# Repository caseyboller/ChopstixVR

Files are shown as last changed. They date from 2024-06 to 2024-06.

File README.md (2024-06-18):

A prototype I made in 2020 for a haptic chopstick to be used in VR, developed from PCB to Unity/Arduino.

Prototype
 
[Design](https://github.com/caseyboller/ChopstixVR/assets/36660680/1214c257-8176-43c2-80a8-be5d32b23608)

[CAD design](https://github.com/caseyboller/ChopstixVR/assets/36660680/7751c19b-aa32-42bb-81e6-dfa4c7f0dddc)

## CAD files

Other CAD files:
case/Chopstix.f3z
case/Control Board.f3z

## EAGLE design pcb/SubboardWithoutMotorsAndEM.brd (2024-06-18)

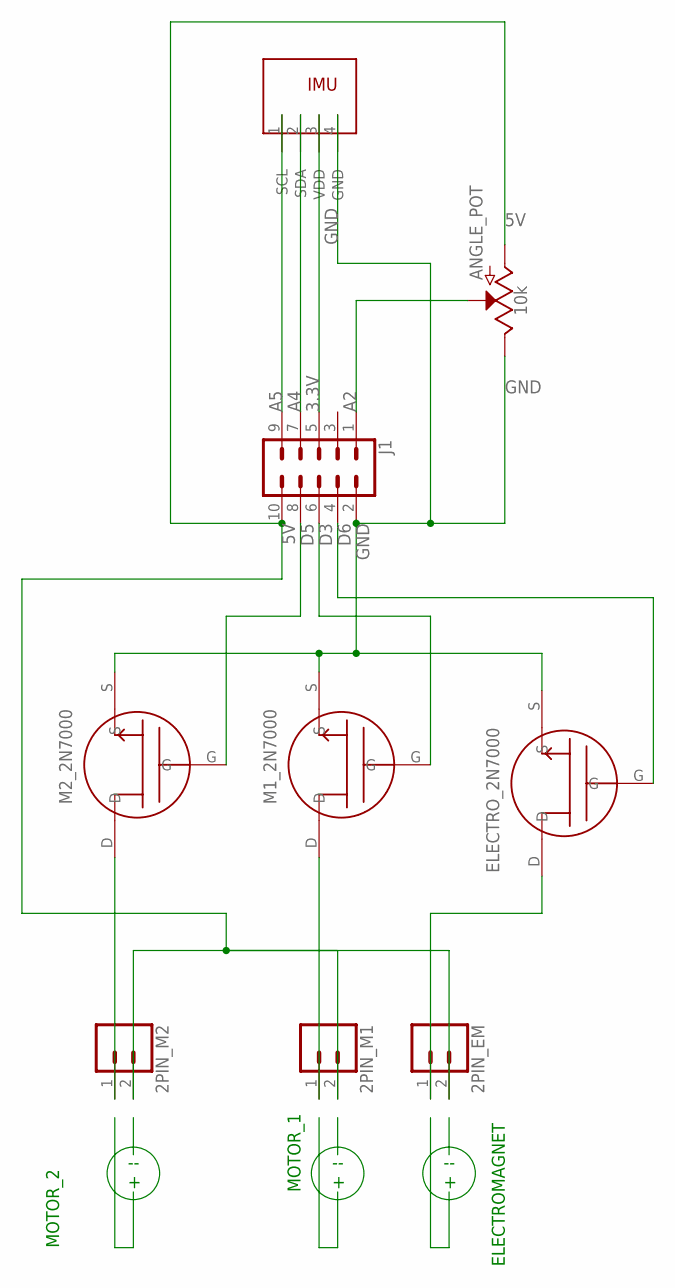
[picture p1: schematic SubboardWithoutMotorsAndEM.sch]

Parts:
2PIN_EM, 2PIN_M1, 2PIN_M2: CONN_02; 1X02
ANGLE_POT: 10k; POT-PTH-ALPS-KIT
ELECTRO_2N7000: 2N7000_N_FET
J1: CONN_05X2SHD; 2X5-SHROUDED
M1_2N7000, M2_2N7000: 2N7000_N_FET
U$1: MPU-9250

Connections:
3.3V: J1.5, U$1.3 (VDD)
5V: 2PIN_EM.2, 2PIN_M1.2, 2PIN_M2.2, ANGLE_POT.P$3 (A), J1.10
A2: ANGLE_POT.P$2 (S), J1.1
A4: J1.7, U$1.2 (SDA)
A5: J1.9, U$1.1 (SCL)
D3: J1.6, M1_2N7000.G
D5: J1.8, M2_2N7000.G
D6: ELECTRO_2N7000.G, J1.4
GND: ANGLE_POT.P$1 (E), ELECTRO_2N7000.S, J1.2, M1_2N7000.S, M2_2N7000.S, U$1.4 (GND)
unnamed: 2PIN_M2.1, M2_2N7000.D
unnamed: 2PIN_M1.1, M1_2N7000.D
unnamed: 2PIN_EM.1, ELECTRO_2N7000.D

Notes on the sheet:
MOTOR_2
MOTOR_1
ELECTROMAGNET
-- +

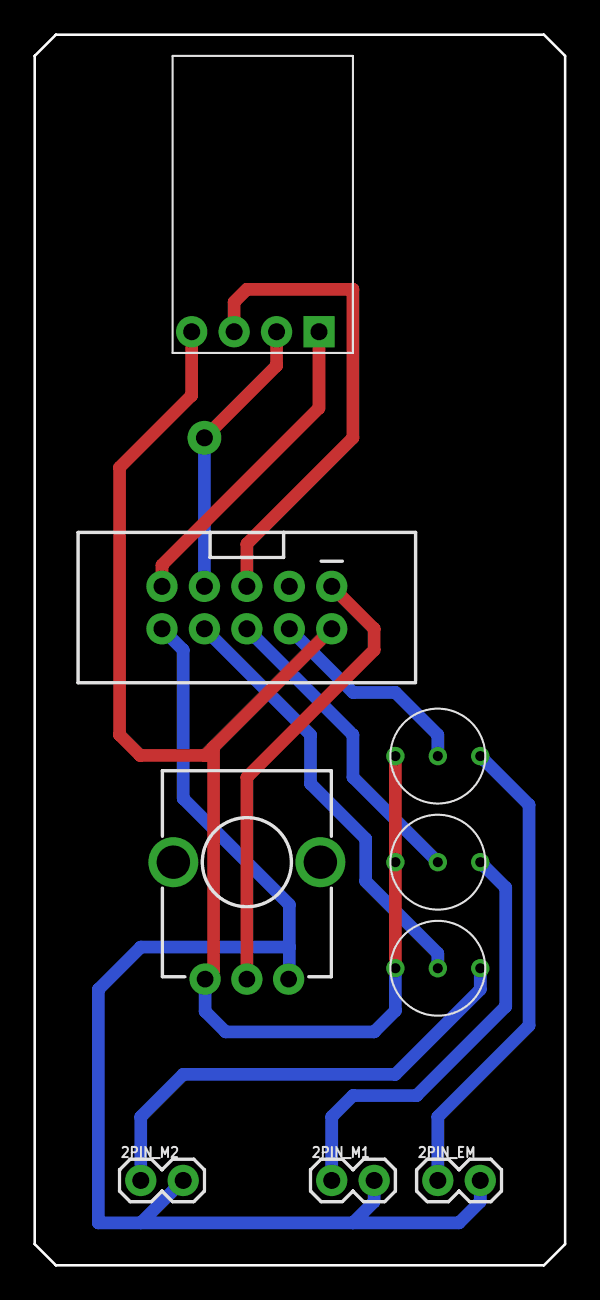
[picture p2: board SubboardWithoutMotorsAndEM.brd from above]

Board: 2 copper layers, 31.7 x 73.7 mm, 9 parts (0 on the bottom side), 12 nets.

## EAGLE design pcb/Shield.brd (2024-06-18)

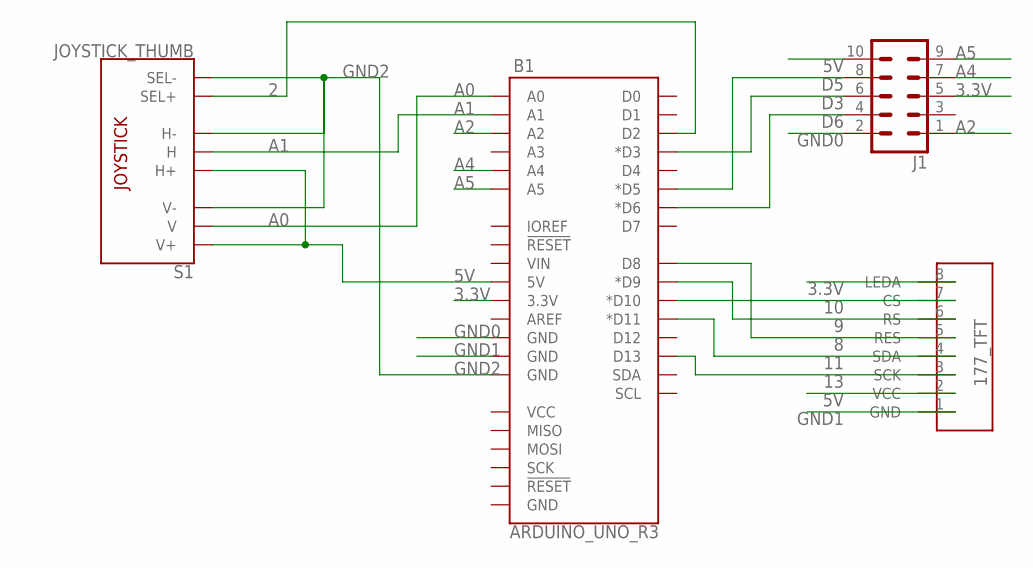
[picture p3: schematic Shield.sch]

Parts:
1.77_TFT: TFT_DISPL_1.77"; TFT_DISP
B1: ARDUINO_UNO_R3; ARDUINO_R3
J1: CONN_05X2SHD; 2X5-SHROUDED
S1: JOYSTICK_THUMB; JOYSTICK

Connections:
2: B1.D2, S1.B1A (SEL+)
3.3V: 1.77_TFT.8 (LEDA), B1.3.3V, J1.5
5V: 1.77_TFT.2 (VCC), B1.5V, J1.10, S1.H1 (H+), S1.V1 (V+)
8: 1.77_TFT.5 (RES), B1.D8
9: 1.77_TFT.6 (RS), B1.D9 (*D9)
10: 1.77_TFT.7 (CS), B1.D10 (*D10)
11: 1.77_TFT.4 (SDA), B1.D11 (*D11)
13: 1.77_TFT.3 (SCK), B1.D13
A0: B1.A0, S1.V2 (V)
A1: B1.A1, S1.H2 (H)
A2: B1.A2, J1.1
A4: B1.A4, J1.7
A5: B1.A5, J1.9
D3: B1.D3 (*D3), J1.6
D5: B1.D5 (*D5), J1.8
D6: B1.D6 (*D6), J1.4
GND0: B1.GND@4 (GND), J1.2
GND1: 1.77_TFT.1 (GND), B1.GND@3 (GND)
GND2: B1.GND@2 (GND), S1.B2A (SEL-), S1.H3 (H-), S1.V3 (V-)

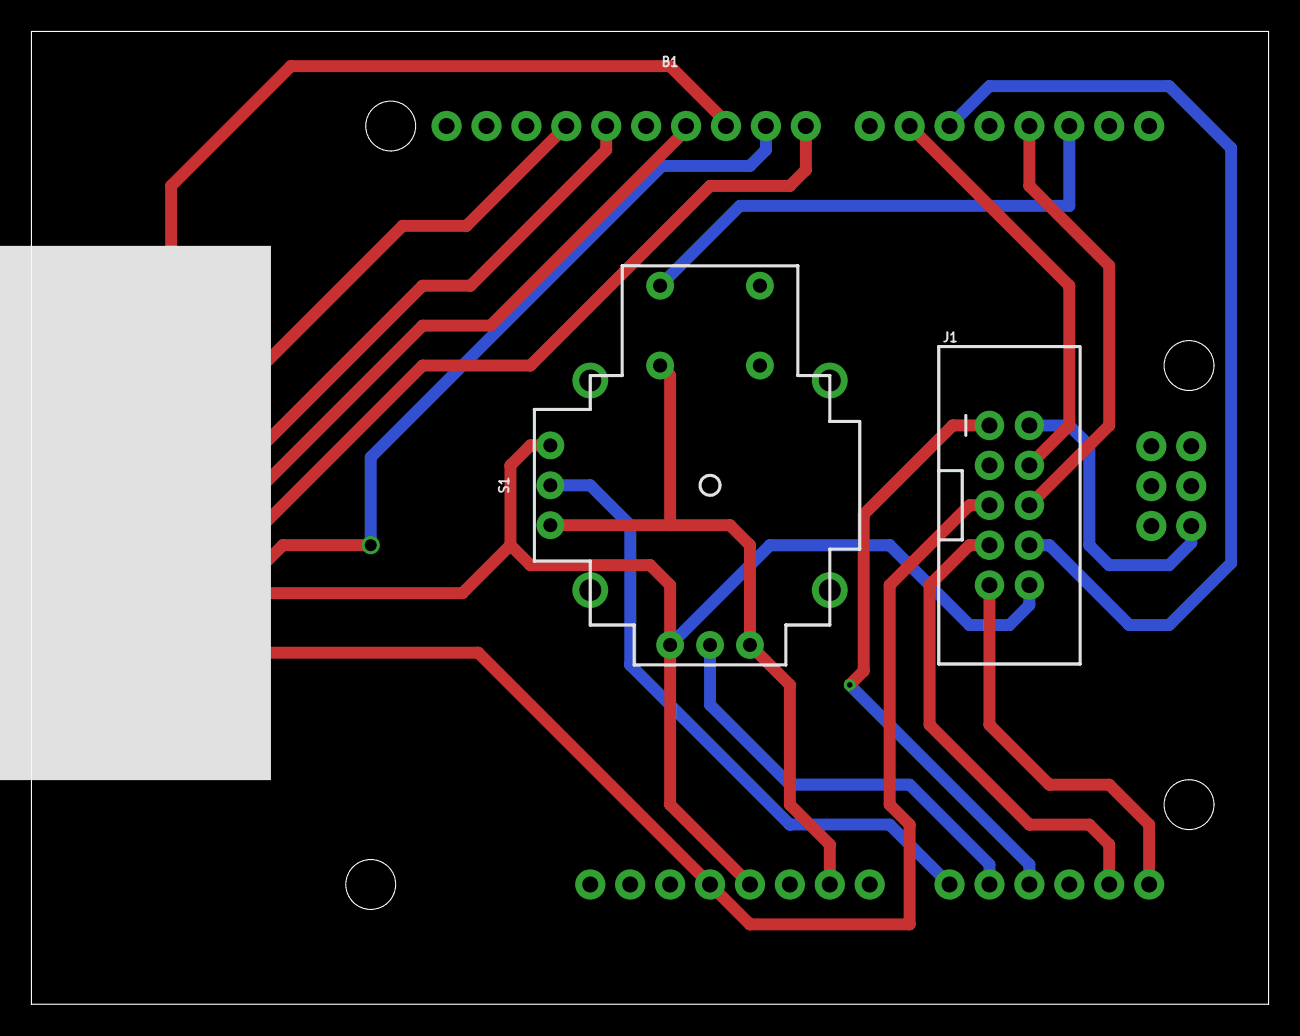
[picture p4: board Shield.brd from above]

Board: 2 copper layers, 78.7 x 61.9 mm, 4 parts (0 on the bottom side), 19 nets.

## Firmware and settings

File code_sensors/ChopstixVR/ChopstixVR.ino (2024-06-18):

/* Significantly based on:
 MPU9250 Basic Example Code
 by: Kris Winer
 date: April 1, 2014
 license: Beerware - Use this code however you'd like. If you
 find it useful you can buy me a beer some time.
 Modified by Brent Wilkins July 19, 2016

 Demonstrate basic MPU-9250 functionality including parameterizing the register
 addresses, initializing the sensor, getting properly scaled accelerometer,
 gyroscope, and magnetometer data out. Added display functions to allow display
 to on breadboard monitor. Addition of 9 DoF sensor fusion using open source
 Madgwick and Mahony filter algorithms. Sketch runs on the 3.3 V 8 MHz Pro Mini
 and the Teensy 3.1.

 SDA and SCL should have external pull-up resistors (to 3.3V).
 10k resistors are on the EMSENSR-9250 breakout board.

 Hardware setup:
 MPU9250 Breakout --------- Arduino
 VDD ---------------------- 3.3V
 VDDI --------------------- 3.3V
 SDA ----------------------- A4
 SCL ----------------------- A5
 GND ---------------------- GND
 */

#include "quaternionFilters.h"
#include "MPU9250.h"

#define AHRS true        // Set to false for basic data read
#define SerialDebug true // Set to true to get Serial output for debugging

// Pin definitions
int intPin = 12; // These can be changed, 2 and 3 are the Arduinos ext int pins
int myLed = 13;  // Set up pin 13 led for toggling

int fixedArmMotorPin = 5;
int rotatingArmMotorPin = 3;
int electromagPin = 6;


#define I2Cclock 400000
#define I2Cport Wire
#define MPU9250_ADDRESS MPU9250_ADDRESS_AD0 // Use either this line or the next to select which I2C address your device is using
//#define MPU9250_ADDRESS MPU9250_ADDRESS_AD1

MPU9250 myIMU(MPU9250_ADDRESS, I2Cport, I2Cclock);

void setupGyro()
{
  Wire.begin();
  // TWBR = 12;  // 400 kbit/sec I2C speed

  // Set up the interrupt pin, its set as active high, push-pull
  pinMode(intPin, INPUT);
  digitalWrite(intPin, LOW);
  pinMode(myLed, OUTPUT);
  digitalWrite(myLed, HIGH);

  // Read the WHO_AM_I register, this is a good test of communication
  byte c = myIMU.readByte(MPU9250_ADDRESS, WHO_AM_I_MPU9250);
  Serial.print(F("MPU9250 I AM 0x"));
  Serial.print(c, HEX);
  Serial.print(F(" I should be 0x"));
  Serial.println(0x71, HEX);

  if (c == 0x71) // WHO_AM_I should always be 0x71
  {
    Serial.println(F("MPU9250 is online..."));

    // Start by performing self test and reporting values
    myIMU.MPU9250SelfTest(myIMU.selfTest);
    Serial.print(F("x-axis self test: acceleration trim within : "));
    Serial.print(myIMU.selfTest[0], 1);
    Serial.println("% of factory value");
    Serial.print(F("y-axis self test: acceleration trim within : "));
    Serial.print(myIMU.selfTest[1], 1);
    Serial.println("% of factory value");
    Serial.print(F("z-axis self test: acceleration trim within : "));
    Serial.print(myIMU.selfTest[2], 1);
    Serial.println("% of factory value");
    Serial.print(F("x-axis self test: gyration trim within : "));
    Serial.print(myIMU.selfTest[3], 1);
    Serial.println("% of factory value");
    Serial.print(F("y-axis self test: gyration trim within : "));
    Serial.print(myIMU.selfTest[4], 1);
    Serial.println("% of factory value");
    Serial.print(F("z-axis self test: gyration trim within : "));
    Serial.print(myIMU.selfTest[5], 1);
    Serial.println("% of factory value");

    // Calibrate gyro and accelerometers, load biases in bias registers
    myIMU.calibrateMPU9250(myIMU.gyroBias, myIMU.accelBias);
    myIMU.initMPU9250();
    // Initialize device for active mode read of acclerometer, gyroscope, and
    // temperature
    Serial.println("MPU9250 initialized for active data mode....");

    // Read the WHO_AM_I register of the magnetometer, this is a good test of
    // communication
    byte d = myIMU.readByte(AK8963_ADDRESS, WHO_AM_I_AK8963);
    Serial.print("AK8963 ");
    Serial.print("I AM 0x");
    Serial.print(d, HEX);
    Serial.print(" I should be 0x");
    Serial.println(0x48, HEX);

    if (d != 0x48)
    {
      // Communication failed, stop here
      Serial.println(F("Communication failed, abort!"));
      Serial.flush();
      abort();
    }

    // Get magnetometer calibration from AK8963 ROM
    myIMU.initAK8963(myIMU.factoryMagCalibration);
    // Initialize device for active mode read of magnetometer
    Serial.println("AK8963 initialized for active data mode....");

    if (SerialDebug)
    {
      //  Serial.println("Calibration values: ");
      Serial.print("X-Axis factory sensitivity adjustment value ");
      Serial.println(myIMU.factoryMagCalibration[0], 2);
      Serial.print("Y-Axis factory sensitivity adjustment value ");
      Serial.println(myIMU.factoryMagCalibration[1], 2);
      Serial.print("Z-Axis factory sensitivity adjustment value ");
      Serial.println(myIMU.factoryMagCalibration[2], 2);
    }
    // Get sensor resolutions, only need to do this once
    myIMU.getAres();
    myIMU.getGres();
    myIMU.getMres();

    // The next call delays for 4 seconds, and then records about 15 seconds of
    // data to calculate bias and scale.
    //    myIMU.magCalMPU9250(myIMU.magBias, myIMU.magScale);
    Serial.println("AK8963 mag biases (mG)");
    Serial.println(myIMU.magBias[0]);
    Serial.println(myIMU.magBias[1]);
    Serial.println(myIMU.magBias[2]);

    Serial.println("AK8963 mag scale (mG)");
    Serial.println(myIMU.magScale[0]);
    Serial.println(myIMU.magScale[1]);
    Serial.println(myIMU.magScale[2]);
    //    delay(2000); // Add delay to see results before serial spew of data

    if (SerialDebug)
    {
      Serial.println("Magnetometer:");
      Serial.print("X-Axis sensitivity adjustment value ");
      Serial.println(myIMU.factoryMagCalibration[0], 2);
      Serial.print("Y-Axis sensitivity adjustment value ");
      Serial.println(myIMU.factoryMagCalibration[1], 2);
      Serial.print("Z-Axis sensitivity adjustment value ");
      Serial.println(myIMU.factoryMagCalibration[2], 2);
    }

  } // if (c == 0x71)
  else
  {
    Serial.print("Could not connect to MPU9250: 0x");
    Serial.println(c, HEX);

    // Communication failed, stop here
    Serial.println(F("Communication failed, abort!"));
    Serial.flush();
    abort();
  }
}

void setup()
{
  Serial.begin(38400);
  
pinMode(fixedArmMotorPin, OUTPUT);
pinMode(rotatingArmMotorPin, OUTPUT);
pinMode(electromagPin, OUTPUT);

  while (!Serial)
  {
  };
  setupGyro();
}

void readGyro()
{
  // If intPin goes high, all data registers have new data
  // On interrupt, check if data ready interrupt
  if (myIMU.readByte(MPU9250_ADDRESS, INT_STATUS) & 0x01)
  {
    myIMU.readAccelData(myIMU.accelCount); // Read the x/y/z adc values

    // Now we'll calculate the accleration value into actual g's
    // This depends on scale being set
    myIMU.ax = (float)myIMU.accelCount[0] * myIMU.aRes; // - myIMU.accelBias[0];
    myIMU.ay = (float)myIMU.accelCount[1] * myIMU.aRes; // - myIMU.accelBias[1];
    myIMU.az = (float)myIMU.accelCount[2] * myIMU.aRes; // - myIMU.accelBias[2];

    myIMU.readGyroData(myIMU.gyroCount); // Read the x/y/z adc values

    // Calculate the gyro value into actual degrees per second
    // This depends on scale being set
    myIMU.gx = (float)myIMU.gyroCount[0] * myIMU.gRes;
    myIMU.gy = (float)myIMU.gyroCount[1] * myIMU.gRes;
    myIMU.gz = (float)myIMU.gyroCount[2] * myIMU.gRes;

    myIMU.readMagData(myIMU.magCount); // Read the x/y/z adc values

    // Calculate the magnetometer values in milliGauss
    // Include factory calibration per data sheet and user environmental
    // corrections
    // Get actual magnetometer value, this depends on scale being set
    myIMU.mx = (float)myIMU.magCount[0] * myIMU.mRes * myIMU.factoryMagCalibration[0] - myIMU.magBias[0];
    myIMU.my = (float)myIMU.magCount[1] * myIMU.mRes * myIMU.factoryMagCalibration[1] - myIMU.magBias[1];
    myIMU.mz = (float)myIMU.magCount[2] * myIMU.mRes * myIMU.factoryMagCalibration[2] - myIMU.magBias[2];
  } // if (readByte(MPU9250_ADDRESS, INT_STATUS) & 0x01)

  // Must be called before updating quaternions!
  myIMU.updateTime();

  // Sensors x (y)-axis of the accelerometer is aligned with the y (x)-axis of
  // the magnetometer; the magnetometer z-axis (+ down) is opposite to z-axis
  // (+ up) of accelerometer and gyro! We have to make some allowance for this
  // orientationmismatch in feeding the output to the quaternion filter. For the
  // MPU-9250, we have chosen a magnetic rotation that keeps the sensor forward
  // along the x-axis just like in the LSM9DS0 sensor. This rotation can be
  // modified to allow any convenient orientation convention. This is ok by
  // aircraft orientation standards! Pass gyro rate as rad/s
  MahonyQuaternionUpdate(myIMU.ax, myIMU.ay, myIMU.az, myIMU.gx * DEG_TO_RAD,
                         myIMU.gy * DEG_TO_RAD, myIMU.gz * DEG_TO_RAD, myIMU.my,
                         myIMU.mx, myIMU.mz, myIMU.deltat);

  if (!AHRS)
  {
    // myIMU.delt_t = millis() - myIMU.count;
    // if (myIMU.delt_t > 500)
    // {
    //   if(SerialDebug)
    //   {
    //     // Print acceleration values in milligs!
    //     Serial.print("X-acceleration: "); Serial.print(1000 * myIMU.ax);
    //     Serial.print(" mg ");
    //     Serial.print("Y-acceleration: "); Serial.print(1000 * myIMU.ay);
    //     Serial.print(" mg ");
    //     Serial.print("Z-acceleration: "); Serial.print(1000 * myIMU.az);
    //     Serial.println(" mg ");

    //     // Print gyro values in degree/sec
    //     Serial.print("X-gyro rate: "); Serial.print(myIMU.gx, 3);
    //     Serial.print(" degrees/sec ");
    //     Serial.print("Y-gyro rate: "); Serial.print(myIMU.gy, 3);
    //     Serial.print(" degrees/sec ");
    //     Serial.print("Z-gyro rate: "); Serial.print(myIMU.gz, 3);
    //     Serial.println(" degrees/sec");

    //     // Print mag values in degree/sec
    //     Serial.print("X-mag field: "); Serial.print(myIMU.mx);
    //     Serial.print(" mG ");
    //     Serial.print("Y-mag field: "); Serial.print(myIMU.my);
    //     Serial.print(" mG ");
    //     Serial.print("Z-mag field: "); Serial.print(myIMU.mz);
    //     Serial.println(" mG");

    //     myIMU.tempCount = myIMU.readTempData();  // Read the adc values
    //     // Temperature in degrees Centigrade
    //     myIMU.temperature = ((float) myIMU.tempCount) / 333.87 + 21.0;
    //     // Print temperature in degrees Centigrade
    //     Serial.print("Temperature is ");  Serial.print(myIMU.temperature, 1);
    //     Serial.println(" degrees C");
    //   }

    //   myIMU.count = millis();
    //   digitalWrite(myLed, !digitalRead(myLed));  // toggle led
    // } // if (myIMU.delt_t > 500)
  } // if (!AHRS)
  else
  {
    // Serial print and/or display at 0.5 s rate independent of data rates
    myIMU.delt_t = millis() - myIMU.count;

    // update LCD once per half-second independent of read rate
    if (myIMU.delt_t > 100)
    {
      Serial.print("Quaternion:");
      Serial.print(*getQ());
      Serial.print(";");
      Serial.print(*(getQ()+1));
      Serial.print(";");
      Serial.print(*(getQ()+2));
      Serial.print(";");
      Serial.println(*(getQ()+3));
      readPot();

      myIMU.count = millis();
      myIMU.sumCount = 0;
      myIMU.sum = 0;
    } // if (myIMU.delt_t > 500)
  }   // if (AHRS)
}

void readPot()
{
  Serial.print("P:");
  Serial.println(analogRead(A2));
}

void loop()
{
  // interpret incoming signals from Unity
  if (Serial.available() > 0)  {
    String incoming = Serial.readString();
    	String cmd1 = GetValue(incoming, ':', 0);
      String cmd2 = GetValue(incoming, ':', 1);
      int pin;
      if (cmd1 == 'L') {
        pin = rotatingArmMotorPin;
      } else if (cmd1 == 'R') {
        pin = fixedArmMotorPin;
      } else if (cmd1 == 'M') {
        pin = electromagPin;
      }
      if (cmd2 == '0') {
          analogWrite(pin, 0);
      } else if (cmd2 == '1') {
        analogWrite(pin, 255);
      }
  }
  readGyro();
}

String GetValue(String data, char separator, int index) //split strings by delimiters
{
	int found = 0;
	int strIndex[] = {0, -1 };
	int maxIndex = data.length() - 1;
	for (int i = 0; i <= maxIndex && found <= index; i++) {
		if (data.charAt(i) == separator || i == maxIndex) {
			found++;
			strIndex[0] = strIndex[1] + 1;
			strIndex[1] = (i == maxIndex) ? i + 1 : i;
		}
	}
	return found>index ? data.substring(strIndex[0], strIndex[1]) : "";
}

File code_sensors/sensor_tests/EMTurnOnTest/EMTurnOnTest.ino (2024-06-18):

void setup() {
    pinMode( 6 , OUTPUT);  // Must be a PWM pin
  analogWrite( 6 , 0 );  // 60% duty cycle
  Serial.begin(9600);
}

void loop() {
int x;

//for( x = 0 ; x < 154 ; x+=1 ) {
//Serial.println(x);
analogWrite( 6 , 255 );
delay(300);
//}

analogWrite( 6 , 0 );
Serial.println("--------------OFF");
delay(900);
}

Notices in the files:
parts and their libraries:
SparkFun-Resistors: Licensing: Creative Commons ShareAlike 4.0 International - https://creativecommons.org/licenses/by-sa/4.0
